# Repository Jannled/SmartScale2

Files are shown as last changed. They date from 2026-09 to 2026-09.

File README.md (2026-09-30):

# SmartScale 2
Modification of a kitchen scale with an ESP32 and a HX711 on a custom PCB. But you can use
this project for other usecases as well, such as measuring the weight of your bee hive, to
measure things you put in your inventory system, to track the weight of the food bowl for
your pets etc.

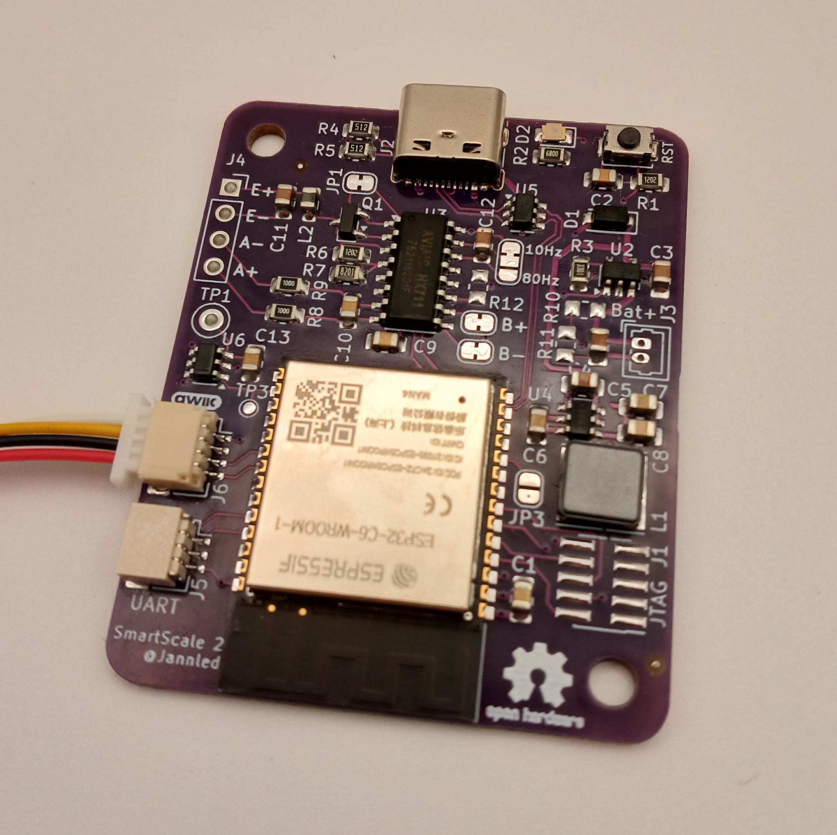
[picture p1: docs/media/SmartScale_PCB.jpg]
Picture of the fully assembled SmartScale 2 PCB


This project is powered by the amazing [ESP32 SvelteKit](https://github.com/theelims/ESP32-sveltekit) framework.

## Software Features
- Automatic hotspot with captive portal if no WiFi is found
- MQTT with auto discovery for HomeAssistant

> [!NOTE]
> Be sure to select `env:esp32-c6-wroom-1-n4` as the PlatformIO project environment/target
> when using the provided PCB.

## Hardware Features
- HX711 as the loadcell measurement ic with additional filtering
- Builtin battery charger for single cell LiPo batteries with status led
- Powered via USB or battery
- Better power efficiency due to buck switching regulator instead of LDO
- WiFi, Bluetooth and Zigbee compatible due to the ESP32-C6
- touch ic for one button
- easily expandable with qwiic connector (I²C)
- debug with the UART port or the JTAG header
- ESD protection for the USB connector

> [!IMPORTANT]
> The **qwiic and UART** port (J5, J6) have no level shifting and are therefore
> **not 5V tolerant** (3.3V only)!
>
> Also the **battery** connector has **no reverse polarity protection**. Check the pinout of your
> Molex PicoBlade connector (sometimes called JST 1.25 by sketchy online stores) before
> you connect the battery!

You can find the [schematic here](/hardware/SmartScale2-Schematic.pdf)

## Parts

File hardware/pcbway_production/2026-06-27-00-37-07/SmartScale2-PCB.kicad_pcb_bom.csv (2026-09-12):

Designator | Quantity | Value | Footprint | Package | MPN | DNP | Mount_Type | Description | KiLib_Generator | Sim.Pins | Sim.Device
C1 | 1 | C | C_0805_2012Metric_Pad1.18x1.45mm_HandSolder |  |  |  | smt | Unpolarized capacitor
C10, C13, C2, C6, C9 | 5 | 100nF | C_0805_2012Metric_Pad1.18x1.45mm_HandSolder |  |  |  | smt | Unpolarized capacitor | SMD_2terminal_chip_molded
C11, C12, C5 | 3 | 10uF | C_0805_2012Metric_Pad1.18x1.45mm_HandSolder |  |  |  | smt | Unpolarized capacitor
C3, C4 | 2 | 4.7uF | C_0805_2012Metric_Pad1.18x1.45mm_HandSolder |  |  |  | smt | Unpolarized capacitor
C7, C8 | 2 | 22uF | C_0805_2012Metric_Pad1.18x1.45mm_HandSolder |  |  |  | smt
D1 | 1 | BZT52C12 | D_SOD-123 |  |  |  | smt | Zener diode
D2 | 1 | LED | LED_0805_2012Metric_Pad1.15x1.40mm_HandSolder |  |  |  | smt | Light emitting diode |  | 1=K 2=A
J1 | 1 | Conn_ARM_JTAG_SWD_10 | PinHeader_2x05_P1.27mm_Vertical_SMD |  |  | Yes | smt | Cortex Debug Connector, standard ARM Cortex-M SWD and JTAG interface
J2 | 1 | USB_C_Receptacle_USB2.0_16P | USB_C_Receptacle_G-Switch_GT-USB-7010ASV |  |  |  | smt | USB 2.0-only 16P Type-C Receptacle connector
J3 | 1 | Conn_01x02 | Molex_PicoBlade_53047-0210_1x02_P1.25mm_Vertical |  |  |  | tht | Generic connector, single row, 01x02, script generated (kicad-library-utils/schlib/autogen/connector/) | connector/Molex
J5 | 1 | Conn_01x03_MountingPin | JST_SH_SM03B-SRSS-TB_1x03-1MP_P1.00mm_Horizontal |  |  |  | smt | Generic connectable mounting pin connector, single row, 01x03, script generated (kicad-library-utils/schlib/autogen/connector/)
J6 | 1 | Conn_01x04_MountingPin | JST_SH_SM04B-SRSS-TB_1x04-1MP_P1.00mm_Horizontal |  |  |  | smt | Generic connectable mounting pin connector, single row, 01x04, script generated (kicad-library-utils/schlib/autogen/connector/)
JP6, JP7 | 2 | Jumper_2_Small_Open | SolderJumper-2_P1.3mm_Open_RoundedPad1.0x1.5mm |  |  |  | tht | Jumper, 2-pole, small symbol, open
L1 | 1 | 3.9uH | L_Taiyo-Yuden_NR-60xx |  |  |  | smt
L2 | 1 | 3.3uH | L_0805_2012Metric_Pad1.05x1.20mm_HandSolder |  |  |  | smt | Inductor
Q1 | 1 | MMBT4403 | SOT-23 |  |  |  | smt | PNP transistor, base/emitter/collector |  | 1=B 2=E 3=C | PNP
R1 | 1 | 10k | R_0805_2012Metric_Pad1.20x1.40mm_HandSolder |  |  |  | smt
R10 | 1 | 33k | R_0805_2012Metric_Pad1.20x1.40mm_HandSolder |  |  | Yes | smt | Resistor | SMD_2terminal_chip_molded
R11 | 1 | 10k | R_0805_2012Metric_Pad1.20x1.40mm_HandSolder |  |  | Yes | smt | Resistor | SMD_2terminal_chip_molded
R12 | 1 | 10k | R_0805_2012Metric_Pad1.20x1.40mm_HandSolder |  |  | Yes | smt | Resistor
R2 | 1 | 470R | R_0805_2012Metric_Pad1.20x1.40mm_HandSolder |  |  |  | smt | Resistor
R3 | 1 | 2k | R_0805_2012Metric_Pad1.20x1.40mm_HandSolder |  |  |  | smt | Resistor
R4, R5 | 2 | 5.1k | R_0805_2012Metric_Pad1.20x1.40mm_HandSolder |  |  |  | smt |  | SMD_2terminal_chip_molded
R6, R7 | 2 | R | R_0805_2012Metric_Pad1.20x1.40mm_HandSolder |  |  |  | smt | Resistor
R8, R9 | 2 | 100R | R_0805_2012Metric_Pad1.20x1.40mm_HandSolder |  |  |  | smt | Resistor
SW1 | 1 | SW_Push_JTP-1130 | SW_Push_SPST_NO_Alps_SKRK |  |  |  | smt | RST
TP1 | 1 | TestPoint | TestPoint_Loop_D2.50mm_Drill1.0mm |  |  |  | tht | test point
U1 | 1 | ESP32-C6-WROOM-1 | ESP32-C6-WROOM-1 |  |  |  | smt | ESP32-C6-WROOM-1/U is a module that supports 2.4 GHz Wi-Fi 6 (802.11 ax), Bluetooth® 5 (LE), Zigbee and Thread (802.15.4)
U2 | 1 | MCP73831-2-OT | SOT-23-5 |  |  |  | smt | Single cell, Li-Ion/Li-Po charge management controller, 4.20V, Tri-State Status Output, in SOT23-5 package
U3 | 1 | HX711 | SOIC-16_3.9x9.9mm_P1.27mm |  |  |  | smt | 24-bit Analog-to-Digital Converter (ADC) for Weight Scales, SOIC-16 (SOP-16)
U4 | 1 | AP63203WU | TSOT-23-6 |  |  |  | smt
U5 | 1 | USBLC6-2SC6 | SOT-23-6 |  |  |  | smt | Very low capacitance ESD protection diode, 2 data-line, SOT-23-6
U6 | 1 | TTP223-BA6 | SOT-23-6 |  |  |  | smt |  | package/gullwing

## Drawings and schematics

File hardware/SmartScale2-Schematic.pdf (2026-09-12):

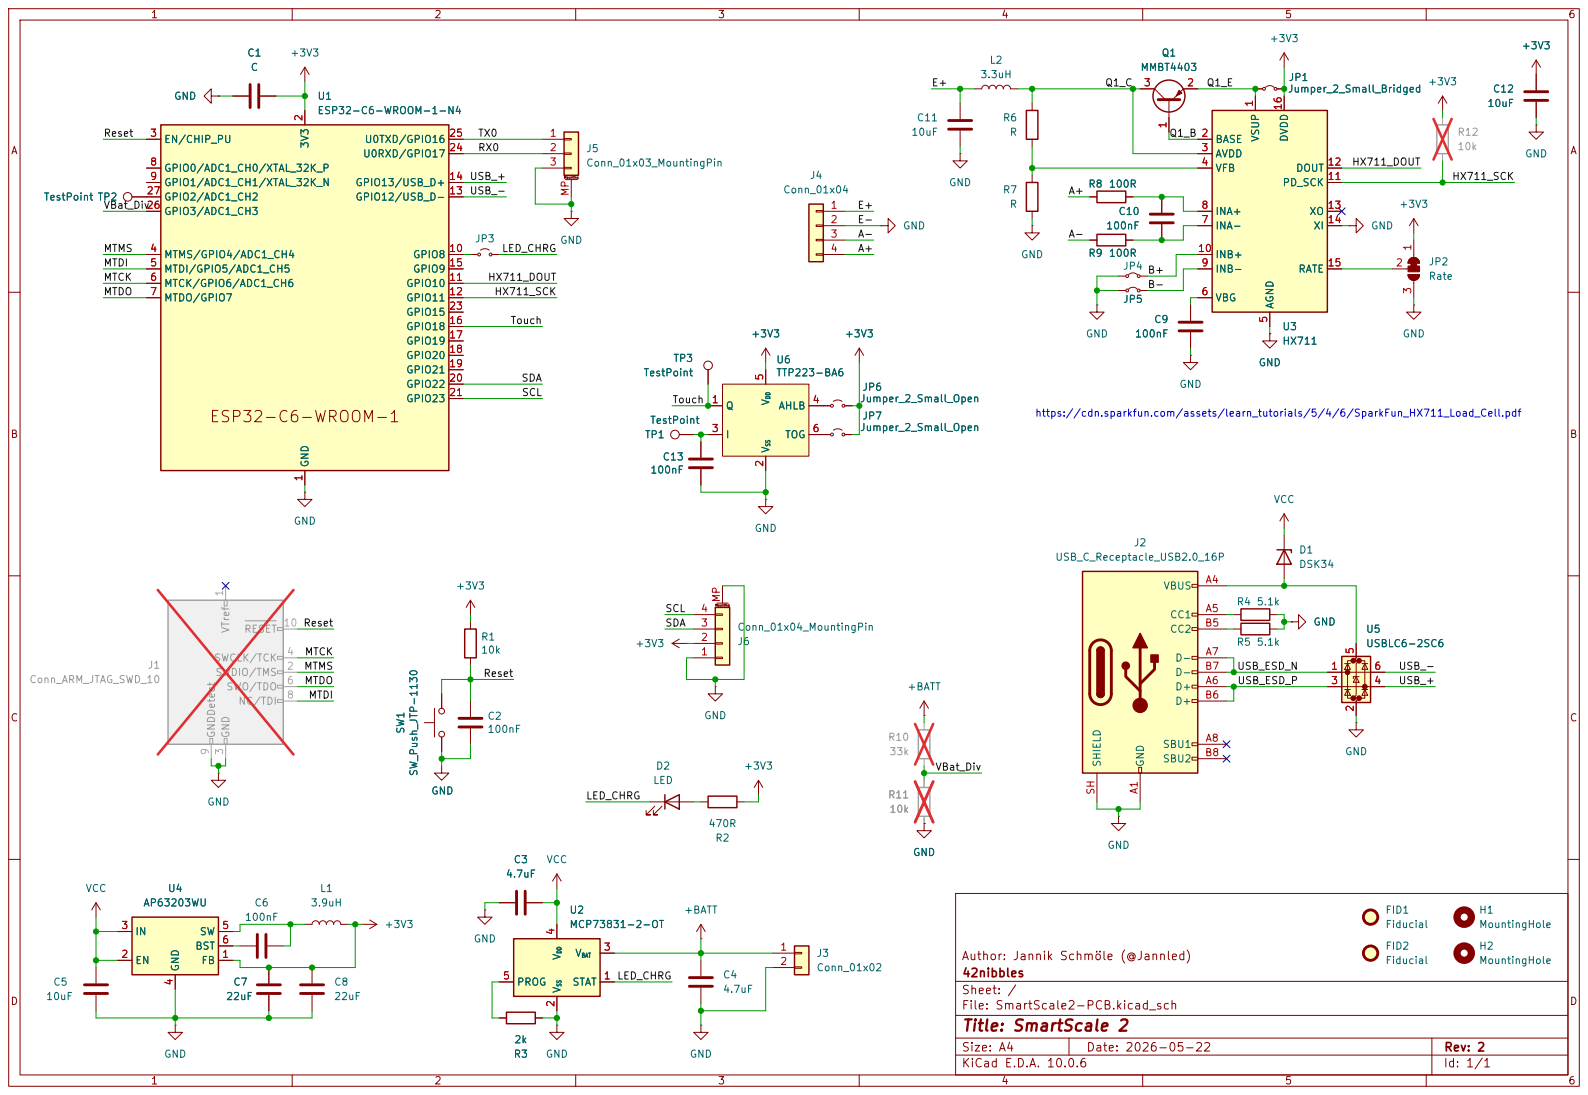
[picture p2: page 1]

Touch MTDI MTCK MTDO

https://cdn.sparkfun.com/assets/learn_tutorials/5/4/6/SparkFun_HX711_Load_Cell.pdf C7
33k GND ESP32-C6-WROOM-1 GND

VDD 4 PROG 5 U2MCP73831-2-OT GND

Size: A4 | Rev: 2
KiCad E.D.A. 10.0.6 | Id: 1/1

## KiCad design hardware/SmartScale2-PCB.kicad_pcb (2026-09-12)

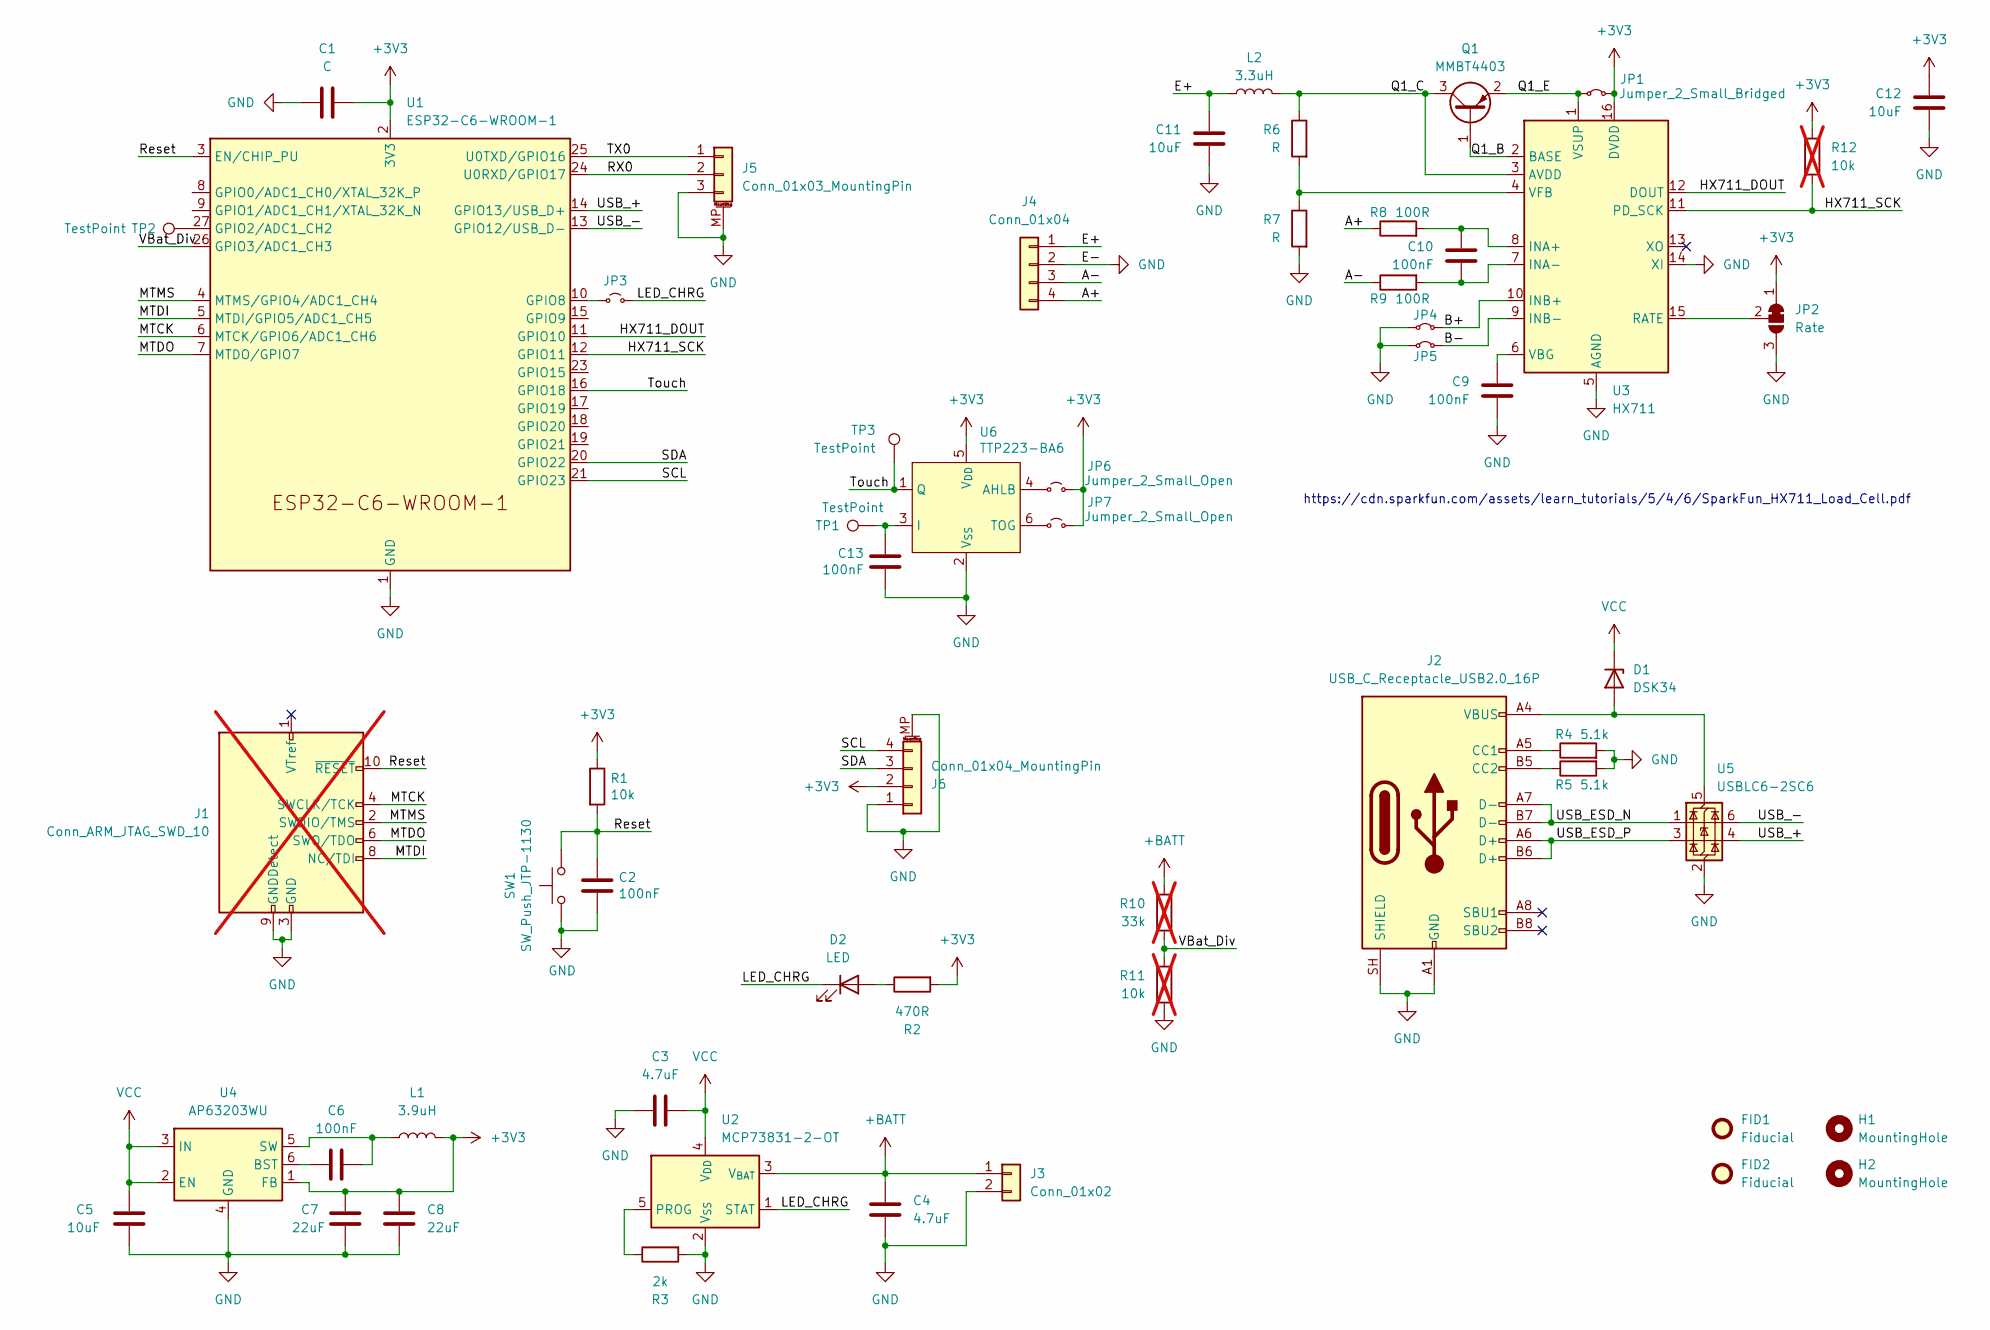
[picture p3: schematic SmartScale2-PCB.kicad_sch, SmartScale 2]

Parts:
C1: C; C_0805_2012Metric_Pad1.18x1.45mm_HandSolder
C2, C6, C9, C10, C13: 100nF; C_0805_2012Metric_Pad1.18x1.45mm_HandSolder
C3, C4: 4.7uF; C_0805_2012Metric_Pad1.18x1.45mm_HandSolder
C5, C11, C12: 10uF; C_0805_2012Metric_Pad1.18x1.45mm_HandSolder
C7, C8: 22uF; C_0805_2012Metric_Pad1.18x1.45mm_HandSolder
D1: DSK34; D_SOD-123
D2: LED; LED_0805_2012Metric_Pad1.15x1.40mm_HandSolder
FID1, FID2: Fiducial; Fiducial_0.5mm_Mask1.5mm
H1, H2: MountingHole; MountingHole_3.2mm_M3_DIN965
J1: Conn_ARM_JTAG_SWD_10; PinHeader_2x05_P1.27mm_Vertical_SMD; not fitted
J2: USB_C_Receptacle_USB2.0_16P; USB_C_Receptacle_G-Switch_GT-USB-7010ASV
J3: Conn_01x02; Molex_PicoBlade_53047-0210_1x02_P1.25mm_Vertical
J4: Conn_01x04; PinSocket_1x04_P2.54mm_Vertical
J5: Conn_01x03_MountingPin; JST_SH_SM03B-SRSS-TB_1x03-1MP_P1.00mm_Horizontal
J6: Conn_01x04_MountingPin; JST_SH_SM04B-SRSS-TB_1x04-1MP_P1.00mm_Horizontal
JP1, JP4, JP5: Jumper_2_Small_Bridged; SolderJumper-2_P1.3mm_Bridged_RoundedPad1.0x1.5mm
JP2: Rate; SolderJumper-3_P1.3mm_Bridged12_RoundedPad1.0x1.5mm_NumberL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
JP3, JP6, JP7: Jumper_2_Small_Open; SolderJumper-2_P1.3mm_Open_RoundedPad1.0x1.5mm
L1: 3.9uH; L_Taiyo-Yuden_NR-60xx
L2: 3.3uH; L_0805_2012Metric_Pad1.05x1.20mm_HandSolder
Q1: MMBT4403; SOT-23
R1: 10k; R_0805_2012Metric_Pad1.20x1.40mm_HandSolder
R2: 470R; R_0805_2012Metric_Pad1.20x1.40mm_HandSolder
R3: 2k; R_0805_2012Metric_Pad1.20x1.40mm_HandSolder
R4, R5: 5.1k; R_0805_2012Metric_Pad1.20x1.40mm_HandSolder
R6, R7: R; R_0805_2012Metric_Pad1.20x1.40mm_HandSolder
R8, R9: 100R; R_0805_2012Metric_Pad1.20x1.40mm_HandSolder
R10: 33k; R_0805_2012Metric_Pad1.20x1.40mm_HandSolder; not fitted
R11, R12: 10k; R_0805_2012Metric_Pad1.20x1.40mm_HandSolder; not fitted
SW1: SW_Push_JTP-1130; SW_Push_SPST_NO_Alps_SKRK
TP1: TestPoint; TestPoint_Loop_D2.50mm_Drill1.0mm
TP2, TP3: TestPoint; TestPoint_Pad_D1.0mm
U1: ESP32-C6-WROOM-1
U2: MCP73831-2-OT; SOT-23-5
U3: HX711; SOIC-16_3.9x9.9mm_P1.27mm
U4: AP63203WU; TSOT-23-6
U5: USBLC6-2SC6; SOT-23-6
U6: TTP223-BA6; SOT-23-6

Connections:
+3V3: C1.2, C7.1, C8.1, C12.1, J6.2, JP1.2 (B), JP2.1 (A), JP6.2 (B), JP7.2 (B), L1.2, R1.1, R2.2, R12.1, U1.2 (3V3), U3.16 (DVDD), U4.1 (FB), U6.5 (V_{DD})
+BATT: C4.1, J3.1, R10.1, U2.3 (V_{BAT})
/A+: J4.4, R8.1
/A-: J4.3, R9.1
/B+: JP4.2 (B), U3.10 (INB+)
/B-: JP5.2 (B), U3.9 (INB-)
/E+: C11.1, J4.1, L2.1
/HX711_DOUT: U1.11 (GPIO10), U3.12 (DOUT)
/HX711_SCK: R12.2, U1.12 (GPIO11), U3.11 (PD_SCK)
/LED_CHRG: D2.1 (K), JP3.2 (B), U2.1 (STAT)
/MTCK: J1.4 (SWCLK/TCK), U1.6 (MTCK/GPIO6/ADC1_CH6)
/MTDI: J1.8 (NC/TDI), U1.5 (MTDI/GPIO5/ADC1_CH5)
/MTDO: J1.6 (SWO/TDO), U1.7 (MTDO/GPIO7)
/MTMS: J1.2 (SWDIO/TMS), U1.4 (MTMS/GPIO4/ADC1_CH4)
/Q1_B: Q1.1 (B), U3.2 (BASE)
/Q1_C: L2.2, Q1.3 (C), R6.1, U3.3 (AVDD)
/Q1_E: JP1.1 (A), Q1.2 (E), U3.1 (VSUP)
/RX0: J5.2, U1.24 (U0RXD/GPIO17)
/Reset: C2.1, J1.10 (~RESET), R1.2, SW1.2, U1.3 (EN/CHIP_PU)
/SCL: J6.4, U1.21 (GPIO23)
/SDA: J6.3, U1.20 (GPIO22)
/TX0: J5.1, U1.25 (U0TXD/GPIO16)
/Touch: TP3.1 (1_1), U1.16 (GPIO18), U6.1 (Q)
/USB_+: U1.14 (GPIO13/USB_D+), U5.4 (I/O2)
/USB_-: U1.13 (GPIO12/USB_D-), U5.6 (I/O1)
/USB_ESD_N: J2.A7 (D-), J2.B7 (D-), U5.1 (I/O1)
/USB_ESD_P: J2.A6 (D+), J2.B6 (D+), U5.3 (I/O2)
/VBat_Div: R10.2, R11.1, U1.26 (GPIO3/ADC1_CH3)
GND: C1.1, C2.2, C3.1, C4.2, C5.2, C7.2, C8.2, C9.2, C11.2, C12.2, C13.2, J1.3 (GND), J1.5 (GND), J1.9 (GNDDetect), J2.A1 (GND), J2.A12 (GND), J2.B1 (GND), J2.B12 (GND), J2.SH (SHIELD), J3.2, J4.2, J5.3, J5.MP (MountPin), J6.1, J6.MP (MountPin), JP2.3 (B), JP4.1 (A), JP5.1 (A), R3.2, R4.2, R5.2, R7.2, R11.2, SW1.1, U1.1 (GND), U1.28 (GND), U1.29 (GND), U2.2 (V_{SS}), U3.5 (AGND), U3.14 (XI), U4.4 (GND), U5.2 (GND), U6.2 (V_{SS})
unnamed: D1.2 (A), J2.A4 (VBUS), J2.A9 (VBUS), J2.B4 (VBUS), J2.B9 (VBUS), U5.5 (VBUS)
unnamed: D2.2 (A), R2.1
unnamed: J2.A5 (CC1), R4.1
unnamed: J2.B5 (CC2), R5.1
unnamed: JP2.2 (C), U3.15 (RATE)
unnamed: JP3.1 (A), U1.10 (GPIO8)
unnamed: JP6.1 (A), U6.4 (AHLB)
unnamed: JP7.1 (A), U6.6 (TOG)
unnamed: TP2.1 (1_1), U1.27 (GPIO2/ADC1_CH2)
unnamed: R3.1, U2.5 (PROG)
unnamed: C10.1, R8.2, U3.8 (INA+)
unnamed: C10.2, R9.2, U3.7 (INA-)
unnamed: C9.1, U3.6 (VBG)
unnamed: R6.2, R7.1, U3.4 (VFB)
unnamed: C6.2, U4.6 (BST)
unnamed: C6.1, L1.1, U4.5 (SW)
unnamed: C13.1, TP1.1 (1_1), U6.3 (I)
VCC: C3.2, C5.1, D1.1 (K), U2.4 (V_{DD}), U4.2 (EN), U4.3 (IN)

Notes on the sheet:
https://cdn.sparkfun.com/assets/learn_tutorials/5/4/6/SparkFun_HX711_Load_Cell.pdf

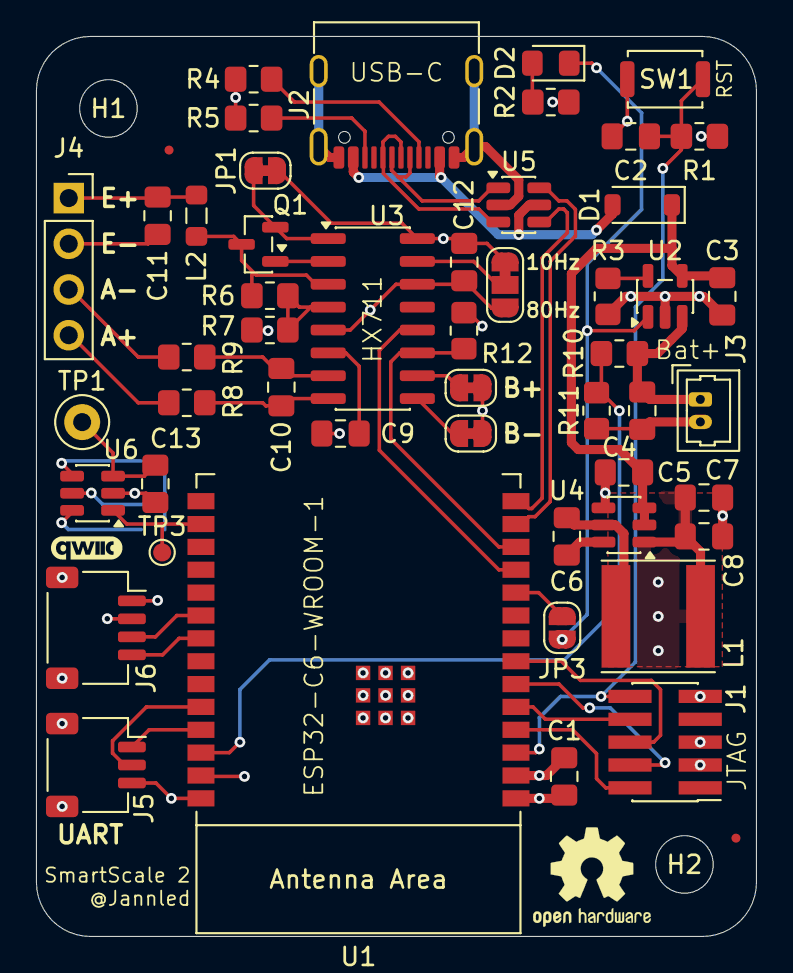
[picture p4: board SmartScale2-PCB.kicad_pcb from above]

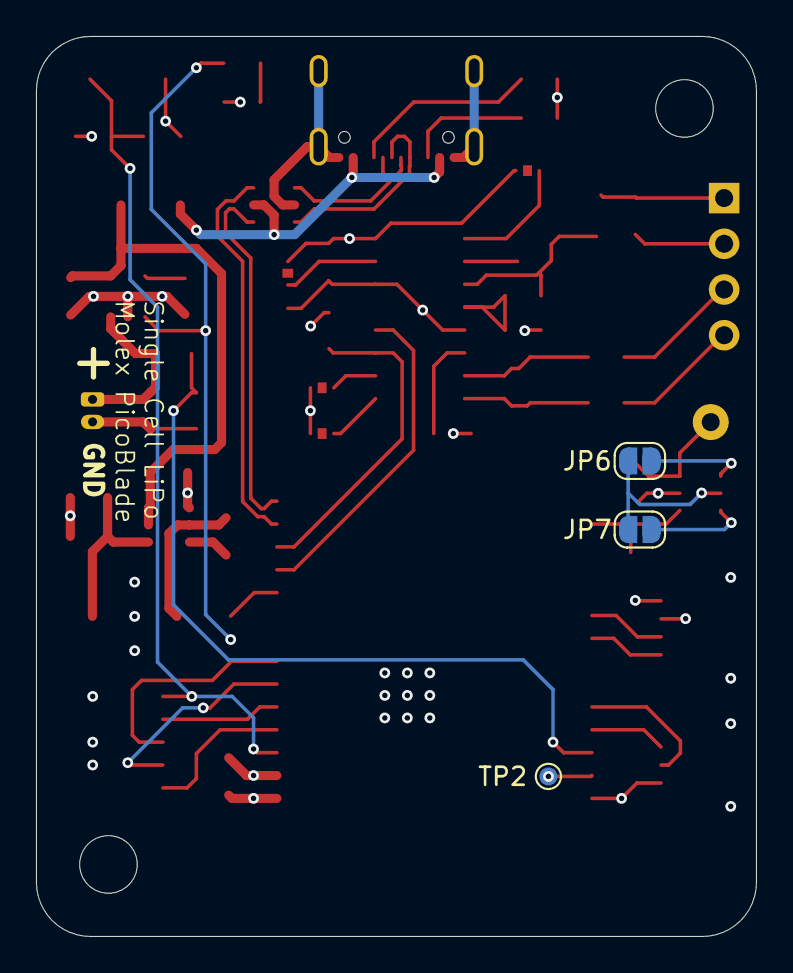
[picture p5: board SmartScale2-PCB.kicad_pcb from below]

Board: 4 copper layers, 40.0 x 50.0 mm, 57 parts (3 on the bottom side), 47 nets.

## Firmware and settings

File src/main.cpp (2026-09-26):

/**
 *   ESP32 SvelteKit
 *
 *   A simple, secure and extensible framework for IoT projects for ESP32 platforms
 *   with responsive Sveltekit front-end built with TailwindCSS and DaisyUI.
 *   https://github.com/theelims/ESP32-sveltekit
 *
 *   Copyright (C) 2018 - 2023 rjwats
 *   Copyright (C) 2023 - 2025 theelims
 *
 *   All Rights Reserved. This software may be modified and distributed under
 *   the terms of the LGPL v3 license. See the LICENSE file for details.
 **/

#include <ESP32SvelteKit.h>
#include <PsychicHttpServer.h>

#ifdef ENABLE_DISPLAY
#include <U8g2lib.h>
#endif

#include "Service/ScaleService.hpp"
#include "Service/ScaleMqttSettingsService.hpp"

#define SERIAL_BAUD_RATE 115200

PsychicHttpServer server;

ESP32SvelteKit esp32sveltekit(&server, 70);

const int LOADCELL_DOUT_PIN = 10;
const int LOADCELL_SCK_PIN = 11;
const long LOADCELL_OFFSET = 570000;//50682624;
const long LOADCELL_DIVIDER = 1; //5895655;
HX711 loadcell = HX711();

#ifdef ENABLE_DISPLAY
#define OLED_DISPLAY_SDA 22
#define OLED_DISPLAY_SCL 23
#define DISPLAY_HEADER_HEIGHT 10
U8G2_SSD1306_128X64_NONAME_2_HW_I2C u8g2(
	U8G2_R0, 255, OLED_DISPLAY_SCL, OLED_DISPLAY_SDA // rotation, reset, scl, sda
);
#endif

ScaleMqttSettingsService scaleMqttSettingsService = ScaleMqttSettingsService(
	&server,
	&esp32sveltekit);

ScaleService scaleService = ScaleService(
	&server,
	&esp32sveltekit,
	&scaleMqttSettingsService,
	&loadcell);

void setup()
{
	// start serial and filesystem
	Serial.begin(SERIAL_BAUD_RATE);

	// Initialize the load cell hardware
	loadcell.begin(LOADCELL_DOUT_PIN, LOADCELL_SCK_PIN);
	loadcell.set_scale(LOADCELL_DIVIDER);
	loadcell.set_offset(LOADCELL_OFFSET);

	Serial.print("Weight: ");
	Serial.println(loadcell.get_units(10), 2);

	// Init the display
	#ifdef ENABLE_DISPLAY
	u8g2.begin();
	#endif

	// start ESP32-SvelteKit
	esp32sveltekit.begin();

	// Launch the Scale Service
	scaleService.begin();
	scaleMqttSettingsService.begin();
}

#ifdef ENABLE_DISPLAY
void updateOLED(float reading)
{
	u8g2.firstPage();
	do
	{
		// Print the weight in gram/kilogram
		static char text[8];
		if(reading < 10000)
			snprintf(text, sizeof(text), "%ldg", (int) reading);
		else
			snprintf(text, sizeof(text), "%.1fk", (float) reading/1000);

		// https://github.com/olikraus/u8g2/wiki/fnticons#siji-pixel-icons
		u8g2.setFont(u8g2_font_siji_t_6x10); // 11px

		// Draw signal strength
		if(WiFi.getMode() == WIFI_MODE_STA || WiFi.getMode() == WIFI_MODE_APSTA)
		{
			if(WiFi.status() == WL_CONNECTED)
			{
				if(WiFi.RSSI() > -2) // implausible signal
					u8g2.drawUTF8(0, DISPLAY_HEADER_HEIGHT, "\uE21B");
				else if(WiFi.RSSI() > -55) // > -55dBm strong signal
					u8g2.drawUTF8(0, DISPLAY_HEADER_HEIGHT, "\uE218");
				else if(WiFi.RSSI() > -70) // > -70dBm medium signal
					u8g2.drawUTF8(0, DISPLAY_HEADER_HEIGHT, "\uE219");
				else // < -70 weak signal
					u8g2.drawUTF8(0, DISPLAY_HEADER_HEIGHT, "\uE21A");
			}
			else
				u8g2.drawUTF8(0, DISPLAY_HEADER_HEIGHT, "\uE217"); // Not connected icon
		}
		else
		{
			u8g2.drawUTF8(0, DISPLAY_HEADER_HEIGHT, "\uE02D"); // "\uE0AC"
		}

		// Draw battery icon
		u8g2.drawUTF8(u8g2.getDisplayWidth() - 12, DISPLAY_HEADER_HEIGHT, "\uE24B"); // \ue242 - \ue24B

		// Draw IP-address
		u8g2.setFont(u8g2_font_littlemissloudonbold_tr); // 8px
		if(WiFi.getMode() == WIFI_MODE_STA || WiFi.getMode() == WIFI_MODE_APSTA)
		{
			u8g2.drawStr(
				12 + 4,
				u8g2.getMaxCharHeight(),
				WiFi.localIP().toString().c_str() // client ip
			);
		}
		else
		{
			u8g2.drawStr(
				12 + 4,
				u8g2.getMaxCharHeight(),
				WiFi.softAPIP().toString().c_str() // access point ip
			);
		}

		// Draw current measured weight
		u8g2.setFont(u8g2_font_t0_40b_tr); // 23px
		u8g2.drawStr(
			u8g2.getDisplayWidth() - u8g2.getStrWidth(text), // x
			DISPLAY_HEADER_HEIGHT + 1 + u8g2.getMaxCharHeight(), // y
			text
		);
	} while (u8g2.nextPage());
}
#endif

void loop()
{
	static unsigned int counter = 0;

	// Read from HX711 ic and put it in JSON
	float reading = loadcell.get_units(10);

	// Push update to state manager
	scaleService.update([&](ScaleState &state) {
		if(state.weight != reading)
		{
			state.weight = reading;
			return StateUpdateResult::CHANGED;
		}

		return StateUpdateResult::UNCHANGED;
	}, "loop");

	// Update the OLED display
	#ifdef ENABLE_DISPLAY
	updateOLED(reading);
	#endif

	counter++;

	// No need to sample at max speed
	delay(500);
}

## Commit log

2026-05-10 Wire in Scale service, add HX711 lib
2026-05-24 Add PCB design files
    [SmartScale2-PCB.kicad_pcb, SmartScale2-PCB.kicad_sch]
2026-06-06 PCB rough layout
    [SmartScale2-PCB.kicad_pcb, SmartScale2-PCB.kicad_sch]
2026-06-07 Add Touch IC, continue layout
    [SmartScale2-PCB.kicad_pcb, SmartScale2-PCB.kicad_sch]
2026-06-10 Push from laptop
    [SmartScale2-PCB.kicad_pcb, SmartScale2-PCB.kicad_sch]
2026-06-12 Finish PCB layout
    [SmartScale2-PCB.kicad_pcb, SmartScale2-PCB.kicad_sch]
2026-06-15 Change inductor, add pin labels
    [SmartScale2-PCB.kicad_pcb, SmartScale2-PCB.kicad_sch]
2026-06-23 Finish PCB
    [SmartScale2-PCB.kicad_pcb, SmartScale2-PCB.kicad_sch]
2026-06-24 Investigate 404
    [SmartScale2-PCB.kicad_pcb_bom.csv, SmartScale2-PCB.kicad_pcb_positions.csv]
2026-06-26 Add jumpers for touch ic pins, render ui on display
    [SmartScale2-PCB.kicad_pcb, SmartScale2-PCB.kicad_pcb_bom.csv, SmartScale2-PCB.kicad_pcb_positions.csv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]
2026-06-26 Add battery connector labels
    [SmartScale2-PCB.kicad_pcb, SmartScale2-PCB.kicad_pcb_bom.csv, SmartScale2-PCB.kicad_pcb_positions.csv]
2026-09-12 Change Diode, reduce firmware size for C6
    [SmartScale2-PCB.kicad_sch]
2026-09-12 Update for the 4MB variant
    [SmartScale2-PCB.kicad_sch]
2026-09-30 Add picture of PCB to Readme
2026-11-09 Fixed wrong value for touch capacitor, touch test code
